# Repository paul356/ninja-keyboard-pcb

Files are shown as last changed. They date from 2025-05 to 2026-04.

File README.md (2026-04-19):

# How to use this project?

This pcb use some symbols and footprints that are not in the default KiCad library. I think the fp cache feature should cache these symbols and footprints. But in case you need them.
1. Keyswitch Kicad Library
2. Additional symbols and footprints are in the folder "user_added".

## 3D Case Design

A FreeCAD 3D model of the keyboard case is included in this project: `keyboard-case.FCStd`. You can open it with [FreeCAD](https://www.freecad.org/) to view, modify, or export the case design for 3D printing or CNC machining.

## License

This project is licensed under the [GNU General Public License v3.0](LICENSE).

You are free to use, study, modify, and distribute this project, provided that any derivative works are also distributed under the same GPL-3.0 license.

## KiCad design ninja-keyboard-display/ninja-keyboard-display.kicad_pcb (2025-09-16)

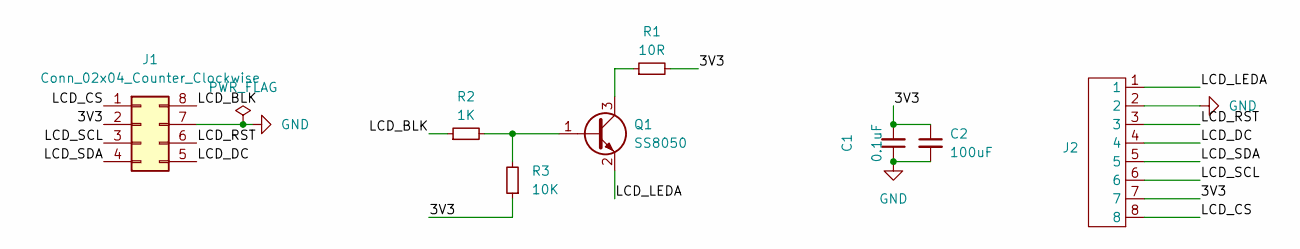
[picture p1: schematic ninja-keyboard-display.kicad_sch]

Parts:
C1: 0.1uF; C_0603_1608Metric; LCSC Part # C14663
C2: 100uF; CP_Elec_6.3x7.7
J1: Conn_02x04_Counter_Clockwise; PinHeader_2x04_P2.54mm_Vertical
J2: HanElectricity 1x8 P0.5mm drawer up-side; LCSC Part # C5362163
Q1: SS8050; SOT-23; LCSC Part # C2150
R1: 10R; R_0603_1608Metric; LCSC Part # C22859
R2: 1K; R_0603_1608Metric; LCSC Part # C21190
R3: 10K; R_0603_1608Metric; LCSC Part # C25804

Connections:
/3V3: C1.2, C2.1, J1.2, J2.7, R1.2, R3.1
/LCD_BLK: J1.8, R2.1
/LCD_CS: J1.1, J2.8
/LCD_DC: J1.5, J2.4
/LCD_LEDA: J2.1, Q1.2 (E)
/LCD_RST: J1.6, J2.3
/LCD_SCL: J1.3, J2.6
/LCD_SDA: J1.4, J2.5
GND: C1.1, C2.2, J1.7, J2.2
unnamed: Q1.1 (B), R2.2, R3.2
unnamed: Q1.3 (C), R1.1

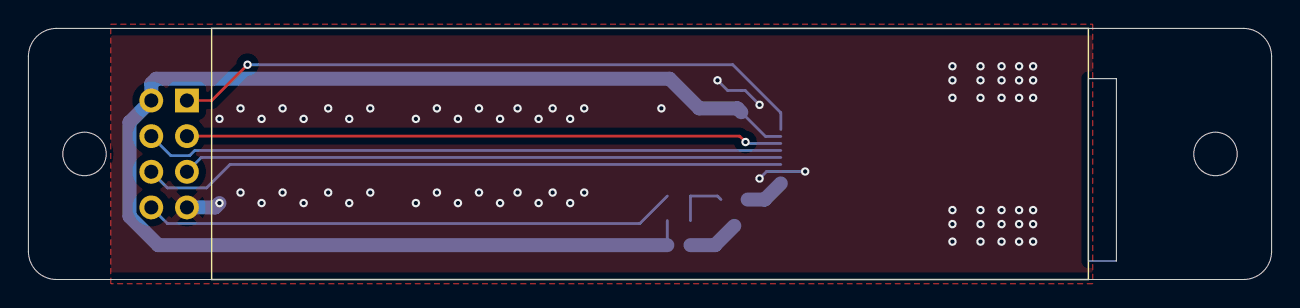
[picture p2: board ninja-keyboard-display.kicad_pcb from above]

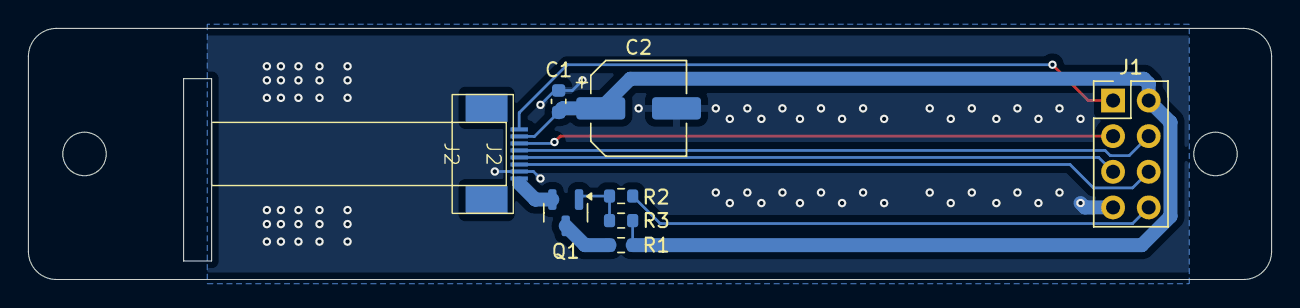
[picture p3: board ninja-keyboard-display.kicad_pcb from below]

Board: 2 copper layers, 88.6 x 17.9 mm, 8 parts (8 on the bottom side), 11 nets.

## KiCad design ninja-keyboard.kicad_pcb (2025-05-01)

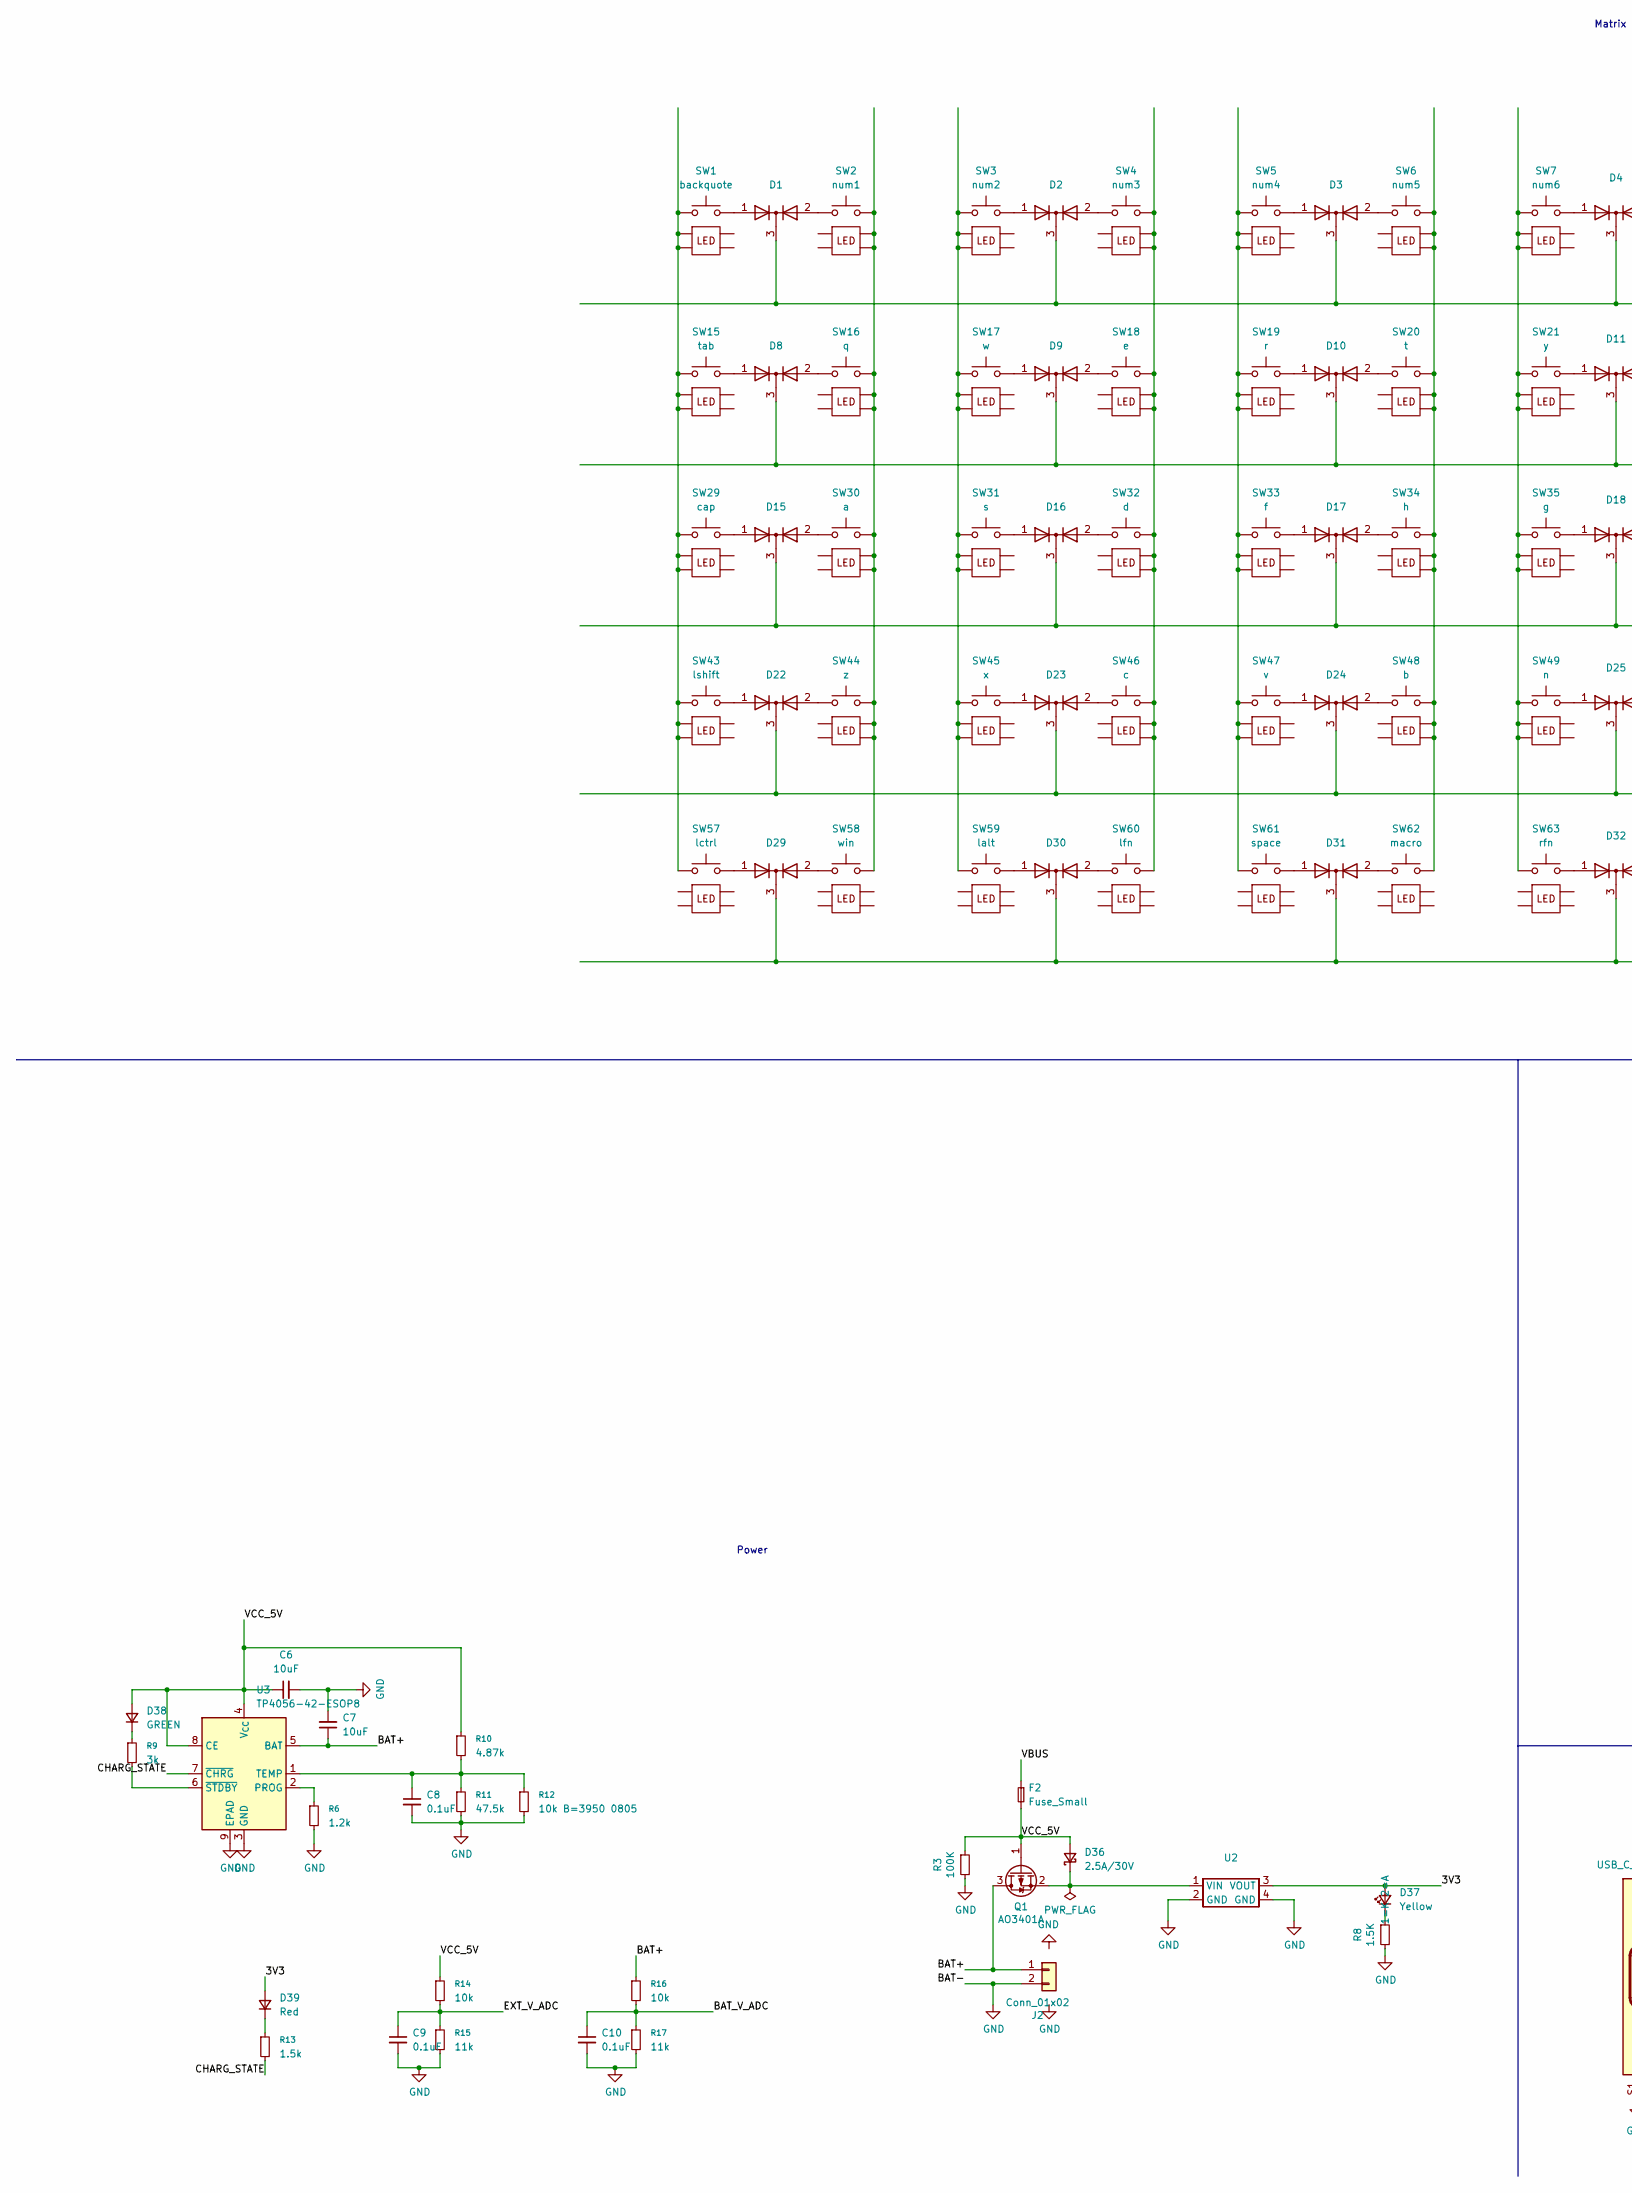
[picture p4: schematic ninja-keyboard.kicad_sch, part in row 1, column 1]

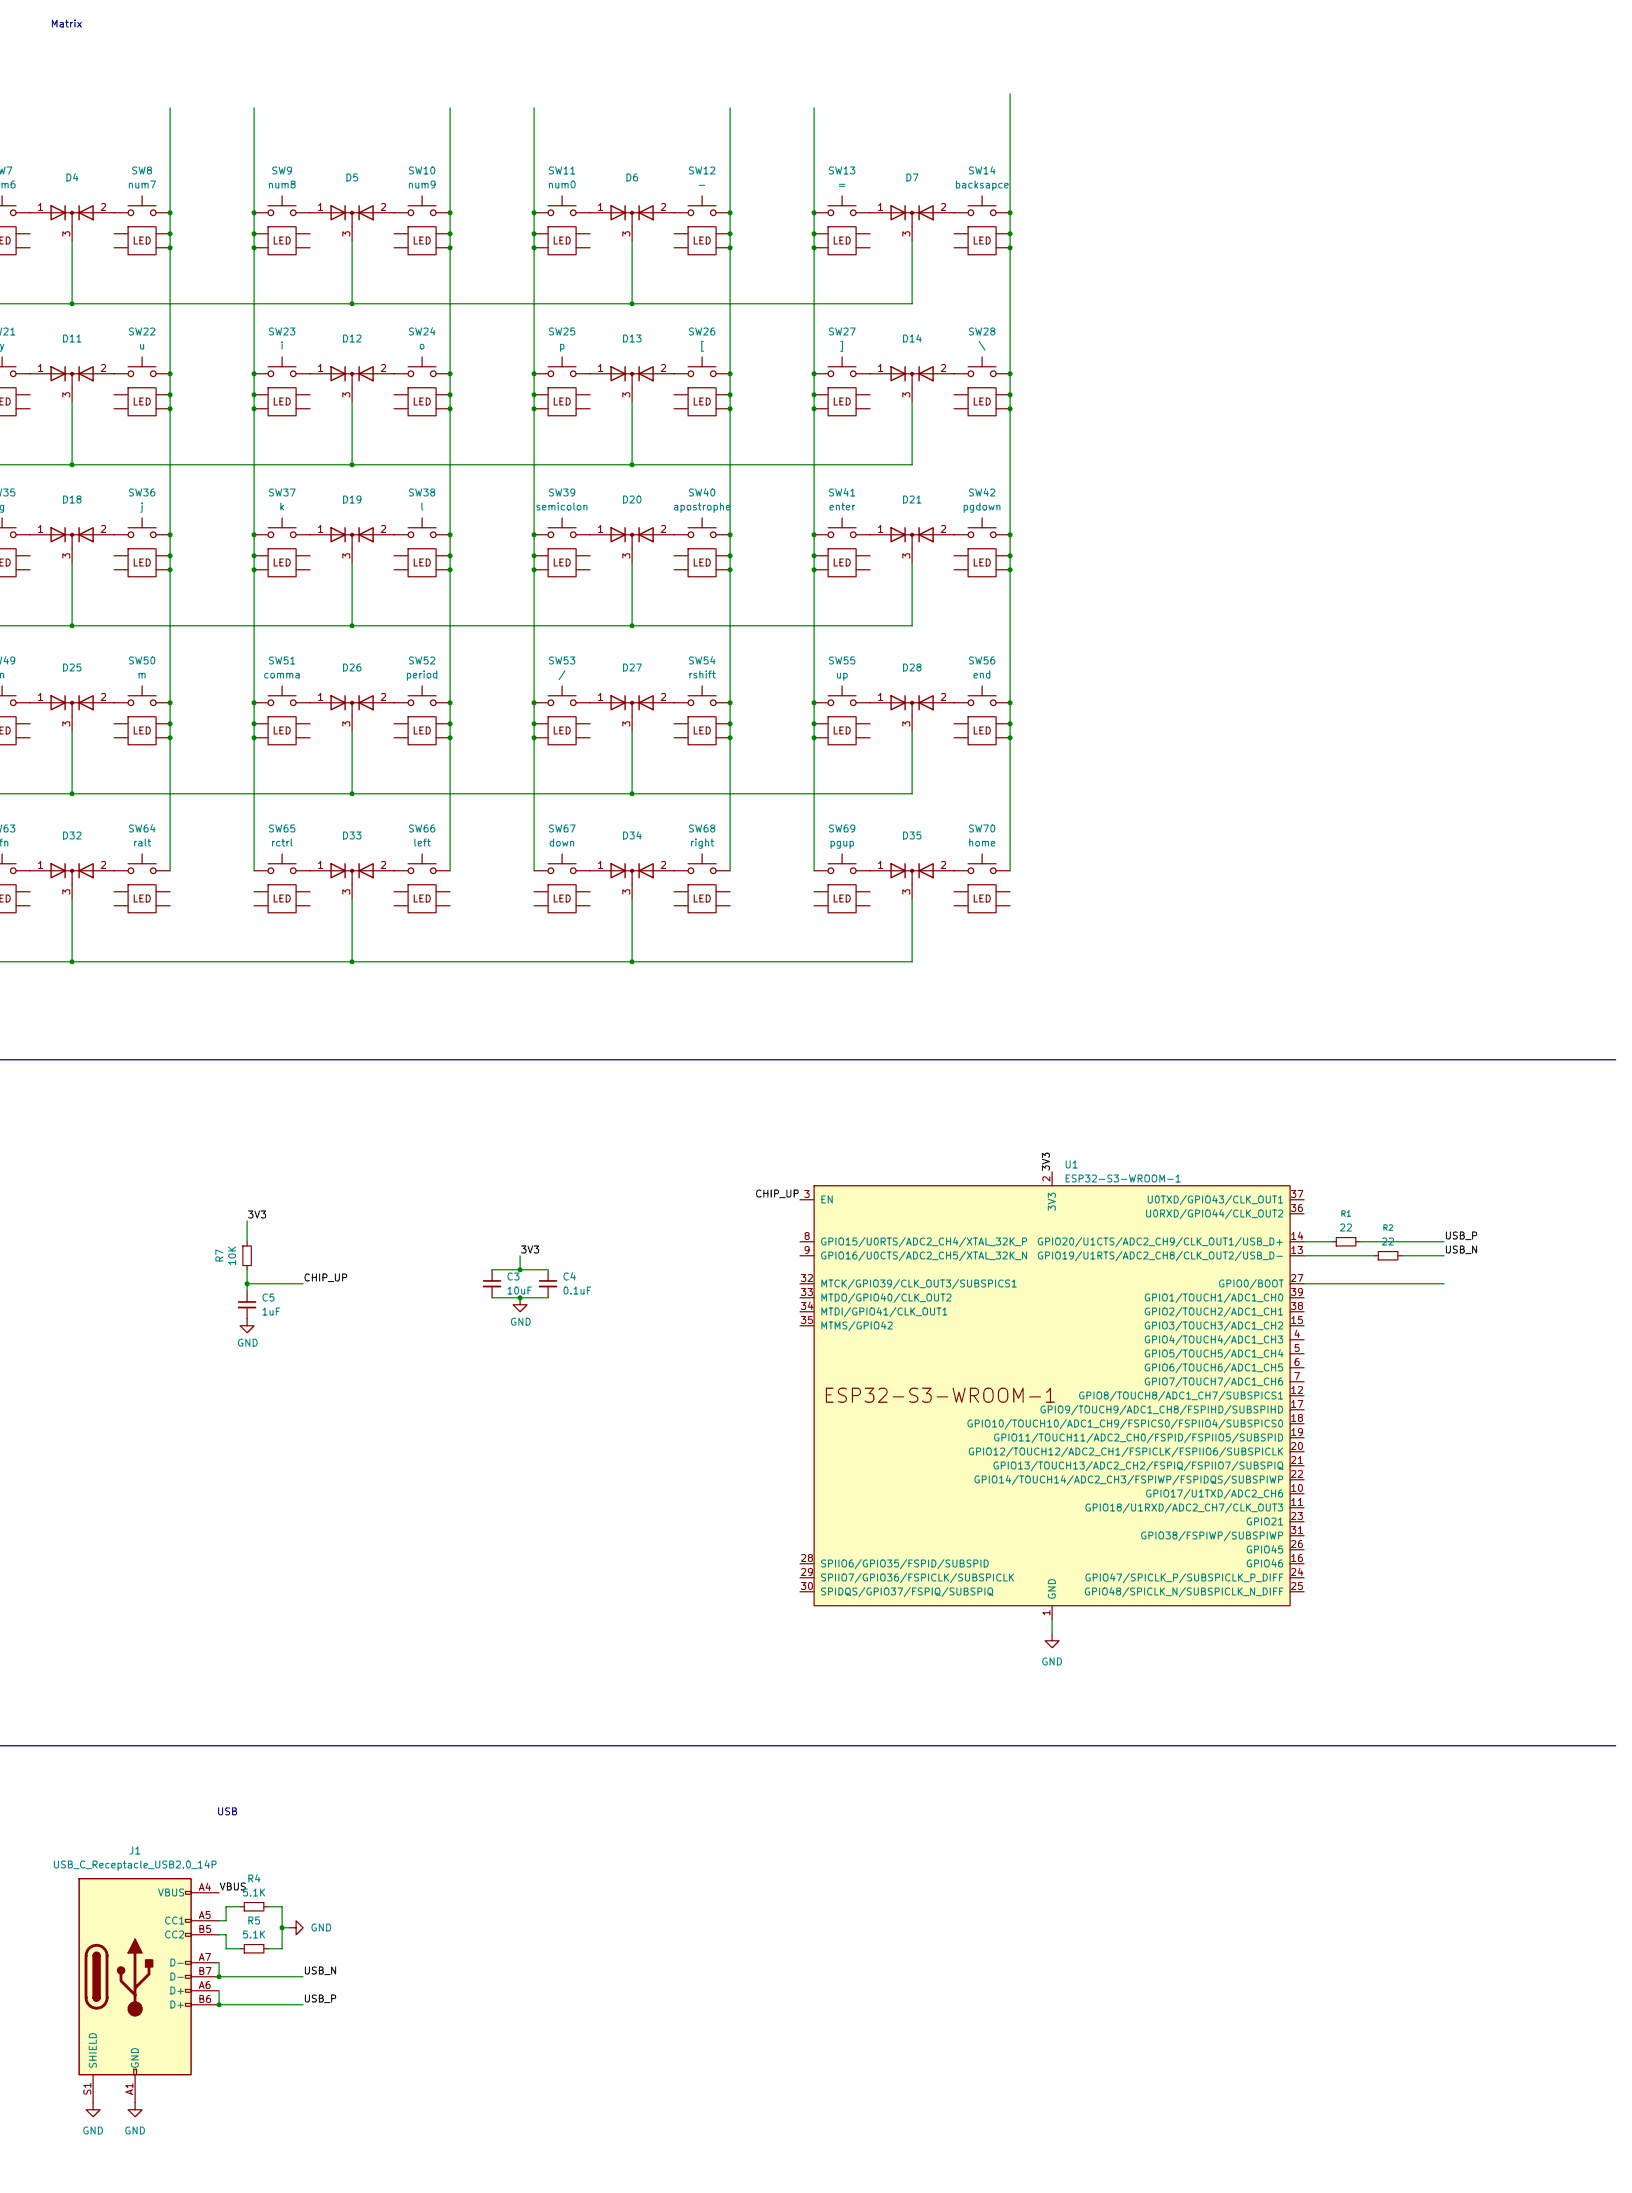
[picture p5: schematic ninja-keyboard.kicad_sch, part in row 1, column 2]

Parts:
C3: 10uF; C_0603_1608Metric; LCSC Part # C19702
C4: 0.1uF; C_0603_1608Metric; LCSC Part # C14663
C5: 1uF; C_0603_1608Metric; LCSC Part # C15849
C6, C7: 10uF; C_0603_1608Metric
C8, C9, C10: 0.1uF; C_0603_1608Metric
D1, D2, D3, D4, D5, D6, D7, D8, D9, D10, D11, D12, D13, D14, D15, D16, D17, D18, D19, D20, D21, D22, D23, D24, D25, D26, D27, D28, D29, D30, D31, D32, D33, D34, D35: SOT-23
D36: 2.5A/30V; D_SOD-123; LCSC Part # C8598
D37: Yellow; LED_0603_1608Metric; LCSC Part # C2286
D38: GREEN; LED_0603_1608Metric
D39: Red; LED_0603_1608Metric
F2: Fuse_Small; Fuse_0805_2012Metric; LCSC Part # C7472578
J1: USB_C_Receptacle_USB2.0_14P; USB_C_Receptacle_HRO_TYPE-C-31-M-12; LCSC Part # C165948
J2: Conn_01x02; PH 1x2 pin gap 2.0mm SMD socket; LCSC Part # C2845379
Q1: AO3401A; SOT-23; LCSC Part # C15127
R1, R2: 22; R_0603_1608Metric
R3: 100K; R_0603_1608Metric; LCSC Part # C25804
R4, R5: 5.1K; R_0603_1608Metric; LCSC Part # C23186
R6: 1.2k; R_0603_1608Metric
R7: 10K; R_0603_1608Metric; LCSC Part # C25804
R8: 1.5K; R_0603_1608Metric; LCSC Part # C25804
R9: 3k; R_0603_1608Metric
R10: 4.87k; R_0603_1608Metric
R11: 47.5k; R_0603_1608Metric
R12: 10k B=3950 0805; R_0805_2012Metric
R13: 1.5k; R_0603_1608Metric
R14, R16: 10k; R_0603_1608Metric
R15, R17: 11k; R_0603_1608Metric
SW1: backquote; SW_Hotswap_Kailh_MX_1.00u with led
SW2: num1; SW_Hotswap_Kailh_MX_1.00u with led
SW3: num2; SW_Hotswap_Kailh_MX_1.00u with led
SW4: num3; SW_Hotswap_Kailh_MX_1.00u with led
SW5: num4; SW_Hotswap_Kailh_MX_1.00u with led
SW6: num5; SW_Hotswap_Kailh_MX_1.00u with led
SW7: num6; SW_Hotswap_Kailh_MX_1.00u with led
SW8: num7; SW_Hotswap_Kailh_MX_1.00u with led
SW9: num8; SW_Hotswap_Kailh_MX_1.00u with led
SW10: num9; SW_Hotswap_Kailh_MX_1.00u with led
SW11: num0; SW_Hotswap_Kailh_MX_1.00u with led
SW12: -; SW_Hotswap_Kailh_MX_1.00u with led
SW13: =; SW_Hotswap_Kailh_MX_1.00u with led
SW14: backsapce; SW_Hotswap_Kailh_MX_1.75u with led
SW15: tab; SW_Hotswap_Kailh_MX_1.50u with led
SW16: q; SW_Hotswap_Kailh_MX_1.00u with led
SW17: w; SW_Hotswap_Kailh_MX_1.00u with led
SW18: e; SW_Hotswap_Kailh_MX_1.00u with led
SW19: r; SW_Hotswap_Kailh_MX_1.00u with led
SW20: t; SW_Hotswap_Kailh_MX_1.00u with led
SW21: y; SW_Hotswap_Kailh_MX_1.00u with led
SW22: u; SW_Hotswap_Kailh_MX_1.00u with led
SW23: i; SW_Hotswap_Kailh_MX_1.00u with led
SW24: o; SW_Hotswap_Kailh_MX_1.00u with led
SW25: p; SW_Hotswap_Kailh_MX_1.00u with led
SW26: [; SW_Hotswap_Kailh_MX_1.00u with led
SW27: ]; SW_Hotswap_Kailh_MX_1.00u with led
SW28: \; SW_Hotswap_Kailh_MX_1.25u with led
SW29: cap; SW_Hotswap_Kailh_MX_1.75u with led
SW30: a; SW_Hotswap_Kailh_MX_1.00u with led
SW31: s; SW_Hotswap_Kailh_MX_1.00u with led
SW32: d; SW_Hotswap_Kailh_MX_1.00u with led
SW33: f; SW_Hotswap_Kailh_MX_1.00u with led
SW34: h; SW_Hotswap_Kailh_MX_1.00u with led
SW35: g; SW_Hotswap_Kailh_MX_1.00u with led
SW36: j; SW_Hotswap_Kailh_MX_1.00u with led
SW37: k; SW_Hotswap_Kailh_MX_1.00u with led
SW38: l; SW_Hotswap_Kailh_MX_1.00u with led
SW39: semicolon; SW_Hotswap_Kailh_MX_1.00u with led
SW40: apostrophe; SW_Hotswap_Kailh_MX_1.00u with led
SW41: enter; SW_Hotswap_Kailh_MX_2.00u with led
SW42: pgdown; SW_Hotswap_Kailh_MX_1.00u with led
SW43: lshift; SW_Hotswap_Kailh_MX_2.25u with led
SW44: z; SW_Hotswap_Kailh_MX_1.00u with led
SW45: x; SW_Hotswap_Kailh_MX_1.00u with led
SW46: c; SW_Hotswap_Kailh_MX_1.00u with led
SW47: v; SW_Hotswap_Kailh_MX_1.00u with led
SW48: b; SW_Hotswap_Kailh_MX_1.00u with led
SW49: n; SW_Hotswap_Kailh_MX_1.00u with led
SW50: m; SW_Hotswap_Kailh_MX_1.00u with led
SW51: comma; SW_Hotswap_Kailh_MX_1.00u with led
SW52: period; SW_Hotswap_Kailh_MX_1.00u with led
SW53: /; SW_Hotswap_Kailh_MX_1.00u with led
SW54: rshift; SW_Hotswap_Kailh_MX_1.50u with led
SW55: up; SW_Hotswap_Kailh_MX_1.00u with led
SW56: end; SW_Hotswap_Kailh_MX_1.00u with led
SW57: lctrl; SW_Hotswap_Kailh_MX_1.25u with led
SW58: win; SW_Hotswap_Kailh_MX_1.25u with led
SW59: lalt; SW_Hotswap_Kailh_MX_1.25u with led
SW60: lfn; SW_Hotswap_Kailh_MX_1.00u with led
SW61: space; SW_Hotswap_Kailh_MX_2.25u with led
SW62: macro; SW_Hotswap_Kailh_MX_2.25u with led
SW63: rfn; SW_Hotswap_Kailh_MX_1.00u with led
SW64: ralt; SW_Hotswap_Kailh_MX_1.25u with led
SW65: rctrl; SW_Hotswap_Kailh_MX_1.25u with led
SW66: left; SW_Hotswap_Kailh_MX_1.00u with led
SW67: down; SW_Hotswap_Kailh_MX_1.00u with led
SW68: right; SW_Hotswap_Kailh_MX_1.00u with led
SW69: pgup; SW_Hotswap_Kailh_MX_1.00u with led
SW70: home; SW_Hotswap_Kailh_MX_1.00u with led
U1: ESP32-S3-WROOM-1
U2: XL63020-3.3
U3: TP4056-42-ESOP8; SOIC-8-1EP_3.9x4.9mm_P1.27mm_EP2.41x3.3mm_ThermalVias

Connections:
/3V3: C3.1, C4.1, D37.2 (A), D39.2 (A), R7.1, U1.2 (3V3), U2.3 (VOUT)
/BAT+: C7.1, J2.1, Q1.3 (D), R16.1, U3.5 (BAT)
/BAT_V_ADC: C10.1, R16.2, R17.1
/CHARG_STATE: R13.2, U3.7 (~CHRG)
/CHIP_UP: C5.1, R7.2, U1.3 (EN)
/EXT_V_ADC: C9.1, R14.2, R15.1
/USB_N: J1.A7 (D-), J1.B7 (D-), R2.2
/USB_P: J1.A6 (D+), J1.B6 (D+), R1.2
/VBUS: F2.1, J1.A4 (VBUS), J1.A9 (VBUS), J1.B4 (VBUS), J1.B9 (VBUS)
/VCC_5V: C6.1, D36.2 (A), D38.2 (A), F2.2, Q1.1 (G), R3.1, R10.1, R14.1, U3.4 (V_{CC}), U3.8 (CE)
GND: C3.2, C4.2, C5.2, C6.2, C7.2, C8.2, C9.2, C10.2, J1.A1 (GND), J1.A12 (GND), J1.B1 (GND), J1.B12 (GND), J1.S1 (SHIELD), J2.2, R3.2, R4.2, R5.2, R6.2, R8.2, R11.2, R12.2, R15.2, R17.2, U1.1 (GND), U1.40 (GND), U1.41 (GND), U2.2 (GND), U2.4 (GND), U3.3 (GND), U3.9 (EPAD)
unnamed: D1.1 (A), SW1.2
unnamed: D1.2 (A), SW2.1
unnamed: D1.3 (K), D2.3 (K), D3.3 (K), D4.3 (K), D5.3 (K), D6.3 (K), D7.3 (K)
unnamed: D2.1 (A), SW3.2
unnamed: D2.2 (A), SW4.1
unnamed: D3.1 (A), SW5.2
unnamed: D3.2 (A), SW6.1
unnamed: D4.1 (A), SW7.2
unnamed: D4.2 (A), SW8.1
unnamed: D5.1 (A), SW9.2
unnamed: D5.2 (A), SW10.1
unnamed: D6.1 (A), SW11.2
unnamed: D6.2 (A), SW12.1
unnamed: D7.1 (A), SW13.2
unnamed: D7.2 (A), SW14.1
unnamed: D8.1 (A), SW15.2
unnamed: D8.2 (A), SW16.1
unnamed: D9.1 (A), SW17.2
unnamed: D9.2 (A), SW18.1
unnamed: D10.1 (A), SW19.2
unnamed: D10.2 (A), SW20.1
unnamed: D8.3 (K), D9.3 (K), D10.3 (K), D11.3 (K), D12.3 (K), D13.3 (K), D14.3 (K)
unnamed: D11.1 (A), SW21.2
unnamed: D11.2 (A), SW22.1
unnamed: D12.1 (A), SW23.2
unnamed: D12.2 (A), SW24.1
unnamed: D13.1 (A), SW25.2
unnamed: D13.2 (A), SW26.1
unnamed: D14.1 (A), SW27.2
unnamed: D14.2 (A), SW28.1
unnamed: D15.1 (A), SW29.2
unnamed: D15.2 (A), SW30.1
unnamed: D15.3 (K), D16.3 (K), D17.3 (K), D18.3 (K), D19.3 (K), D20.3 (K), D21.3 (K)
unnamed: D16.1 (A), SW31.2
unnamed: D16.2 (A), SW32.1
unnamed: D17.1 (A), SW33.2
unnamed: D17.2 (A), SW34.1
unnamed: D18.1 (A), SW35.2
unnamed: D18.2 (A), SW36.1
unnamed: D19.1 (A), SW37.2
unnamed: D19.2 (A), SW38.1
unnamed: D20.1 (A), SW39.2
unnamed: D20.2 (A), SW40.1
unnamed: D21.1 (A), SW41.2
unnamed: D21.2 (A), SW42.1
unnamed: D22.1 (A), SW43.2
unnamed: D22.2 (A), SW44.1
unnamed: D22.3 (K), D23.3 (K), D24.3 (K), D25.3 (K), D26.3 (K), D27.3 (K), D28.3 (K)
unnamed: D23.1 (A), SW45.2
unnamed: D23.2 (A), SW46.1
unnamed: D24.1 (A), SW47.2
unnamed: D24.2 (A), SW48.1
unnamed: D25.1 (A), SW49.2
unnamed: D25.2 (A), SW50.1
unnamed: D26.1 (A), SW51.2
unnamed: D26.2 (A), SW52.1
unnamed: D27.1 (A), SW53.2
unnamed: D27.2 (A), SW54.1
unnamed: D28.1 (A), SW55.2
unnamed: D28.2 (A), SW56.1
unnamed: D29.1 (A), SW57.2
unnamed: D29.2 (A), SW58.1
unnamed: D29.3 (K), D30.3 (K), D31.3 (K), D32.3 (K), D33.3 (K), D34.3 (K), D35.3 (K)
unnamed: D30.1 (A), SW59.2
unnamed: D30.2 (A), SW60.1
unnamed: D31.1 (A), SW61.2
unnamed: D31.2 (A), SW62.1
unnamed: D32.1 (A), SW63.2
unnamed: D32.2 (A), SW64.1
unnamed: D33.1 (A), SW65.2
unnamed: D33.2 (A), SW66.1
unnamed: D34.1 (A), SW67.2
unnamed: D34.2 (A), SW68.1
unnamed: D35.1 (A), SW69.2
unnamed: D35.2 (A), SW70.1
unnamed: D36.1 (K), Q1.2 (S), U2.1 (VIN)
unnamed: D37.1 (K), R8.1
unnamed: D38.1 (K), R9.1
unnamed: D39.1 (K), R13.1
unnamed: J1.A5 (CC1), R4.1
unnamed: J1.B5 (CC2), R5.1
unnamed: SW1.1, SW1.3 (VDD), SW1.4 (DOUT), SW15.1, SW15.3 (VDD), SW15.4 (DOUT), SW29.1, SW29.3 (VDD), SW29.4 (DOUT), SW43.1, SW43.3 (VDD), SW43.4 (DOUT), SW57.1
unnamed: SW10.2, SW10.5 (DIN), SW10.6 (GND), SW24.2, SW24.5 (DIN), SW24.6 (GND), SW38.2, SW38.5 (DIN), SW38.6 (GND), SW52.2, SW52.5 (DIN), SW52.6 (GND), SW66.2
unnamed: SW11.1, SW11.3 (VDD), SW11.4 (DOUT), SW25.1, SW25.3 (VDD), SW25.4 (DOUT), SW39.1, SW39.3 (VDD), SW39.4 (DOUT), SW53.1, SW53.3 (VDD), SW53.4 (DOUT), SW67.1
unnamed: SW12.2, SW12.5 (DIN), SW12.6 (GND), SW26.2, SW26.5 (DIN), SW26.6 (GND), SW40.2, SW40.5 (DIN), SW40.6 (GND), SW54.2, SW54.5 (DIN), SW54.6 (GND), SW68.2
unnamed: SW13.1, SW13.3 (VDD), SW13.4 (DOUT), SW27.1, SW27.3 (VDD), SW27.4 (DOUT), SW41.1, SW41.3 (VDD), SW41.4 (DOUT), SW55.1, SW55.3 (VDD), SW55.4 (DOUT), SW69.1
unnamed: SW14.2, SW14.5 (DIN), SW14.6 (GND), SW28.2, SW28.5 (DIN), SW28.6 (GND), SW42.2, SW42.5 (DIN), SW42.6 (GND), SW56.2, SW56.5 (DIN), SW56.6 (GND), SW70.2
unnamed: SW2.2, SW2.5 (DIN), SW2.6 (GND), SW16.2, SW16.5 (DIN), SW16.6 (GND), SW30.2, SW30.5 (DIN), SW30.6 (GND), SW44.2, SW44.5 (DIN), SW44.6 (GND), SW58.2
unnamed: SW3.1, SW3.3 (VDD), SW3.4 (DOUT), SW17.1, SW17.3 (VDD), SW17.4 (DOUT), SW31.1, SW31.3 (VDD), SW31.4 (DOUT), SW45.1, SW45.3 (VDD), SW45.4 (DOUT), SW59.1
unnamed: SW4.2, SW4.5 (DIN), SW4.6 (GND), SW18.2, SW18.5 (DIN), SW18.6 (GND), SW32.2, SW32.5 (DIN), SW32.6 (GND), SW46.2, SW46.5 (DIN), SW46.6 (GND), SW60.2
unnamed: SW5.1, SW5.3 (VDD), SW5.4 (DOUT), SW19.1, SW19.3 (VDD), SW19.4 (DOUT), SW33.1, SW33.3 (VDD), SW33.4 (DOUT), SW47.1, SW47.3 (VDD), SW47.4 (DOUT), SW61.1
unnamed: SW6.2, SW6.5 (DIN), SW6.6 (GND), SW20.2, SW20.5 (DIN), SW20.6 (GND), SW34.2, SW34.5 (DIN), SW34.6 (GND), SW48.2, SW48.5 (DIN), SW48.6 (GND), SW62.2
unnamed: SW7.1, SW7.3 (VDD), SW7.4 (DOUT), SW21.1, SW21.3 (VDD), SW21.4 (DOUT), SW35.1, SW35.3 (VDD), SW35.4 (DOUT), SW49.1, SW49.3 (VDD), SW49.4 (DOUT), SW63.1
unnamed: SW8.2, SW8.5 (DIN), SW8.6 (GND), SW22.2, SW22.5 (DIN), SW22.6 (GND), SW36.2, SW36.5 (DIN), SW36.6 (GND), SW50.2, SW50.5 (DIN), SW50.6 (GND), SW64.2
unnamed: SW9.1, SW9.3 (VDD), SW9.4 (DOUT), SW23.1, SW23.3 (VDD), SW23.4 (DOUT), SW37.1, SW37.3 (VDD), SW37.4 (DOUT), SW51.1, SW51.3 (VDD), SW51.4 (DOUT), SW65.1
unnamed: R2.1, U1.13 (GPIO19/U1RTS/ADC2_CH8/CLK_OUT2/USB_D-)
unnamed: R1.1, U1.14 (GPIO20/U1CTS/ADC2_CH9/CLK_OUT1/USB_D+)
unnamed: R6.1, U3.2 (PROG)
unnamed: C8.1, R10.2, R11.1, R12.1, U3.1 (TEMP)
unnamed: R9.2, U3.6 (~STDBY)

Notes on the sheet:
Power
Matrix
USB

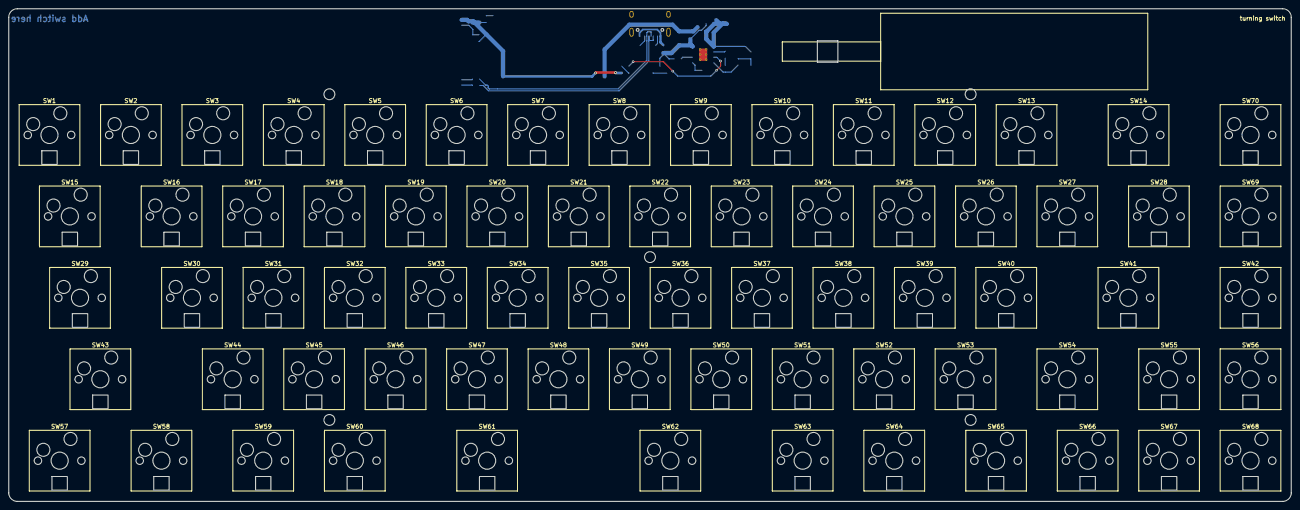
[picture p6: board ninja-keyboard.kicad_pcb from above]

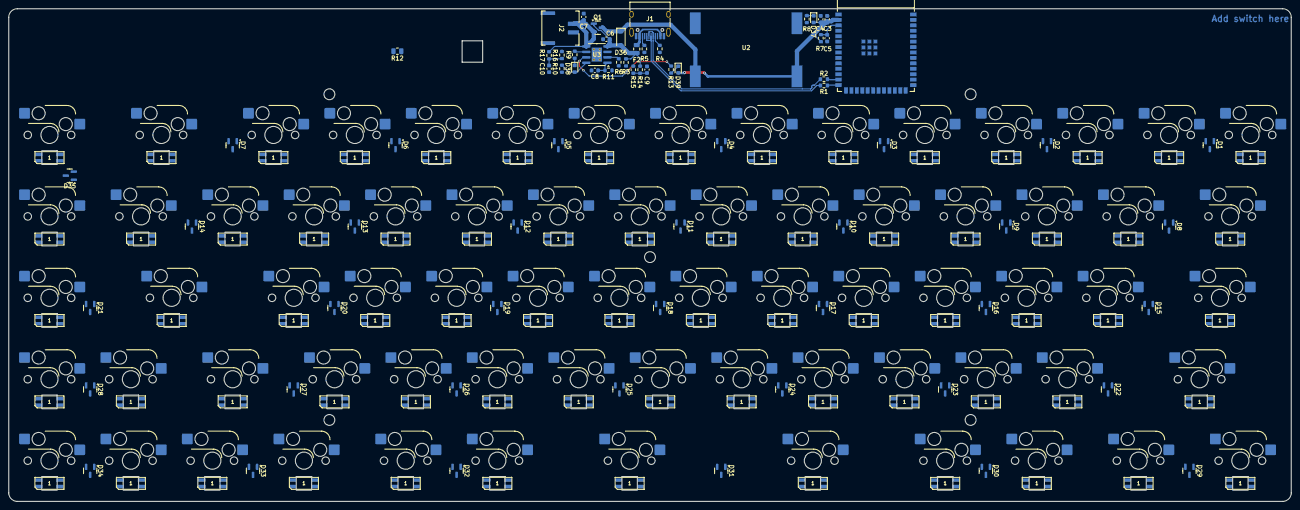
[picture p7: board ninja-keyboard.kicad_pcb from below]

Board: 2 copper layers, 300.0 x 115.3 mm, 141 parts (71 on the bottom side), 111 nets.

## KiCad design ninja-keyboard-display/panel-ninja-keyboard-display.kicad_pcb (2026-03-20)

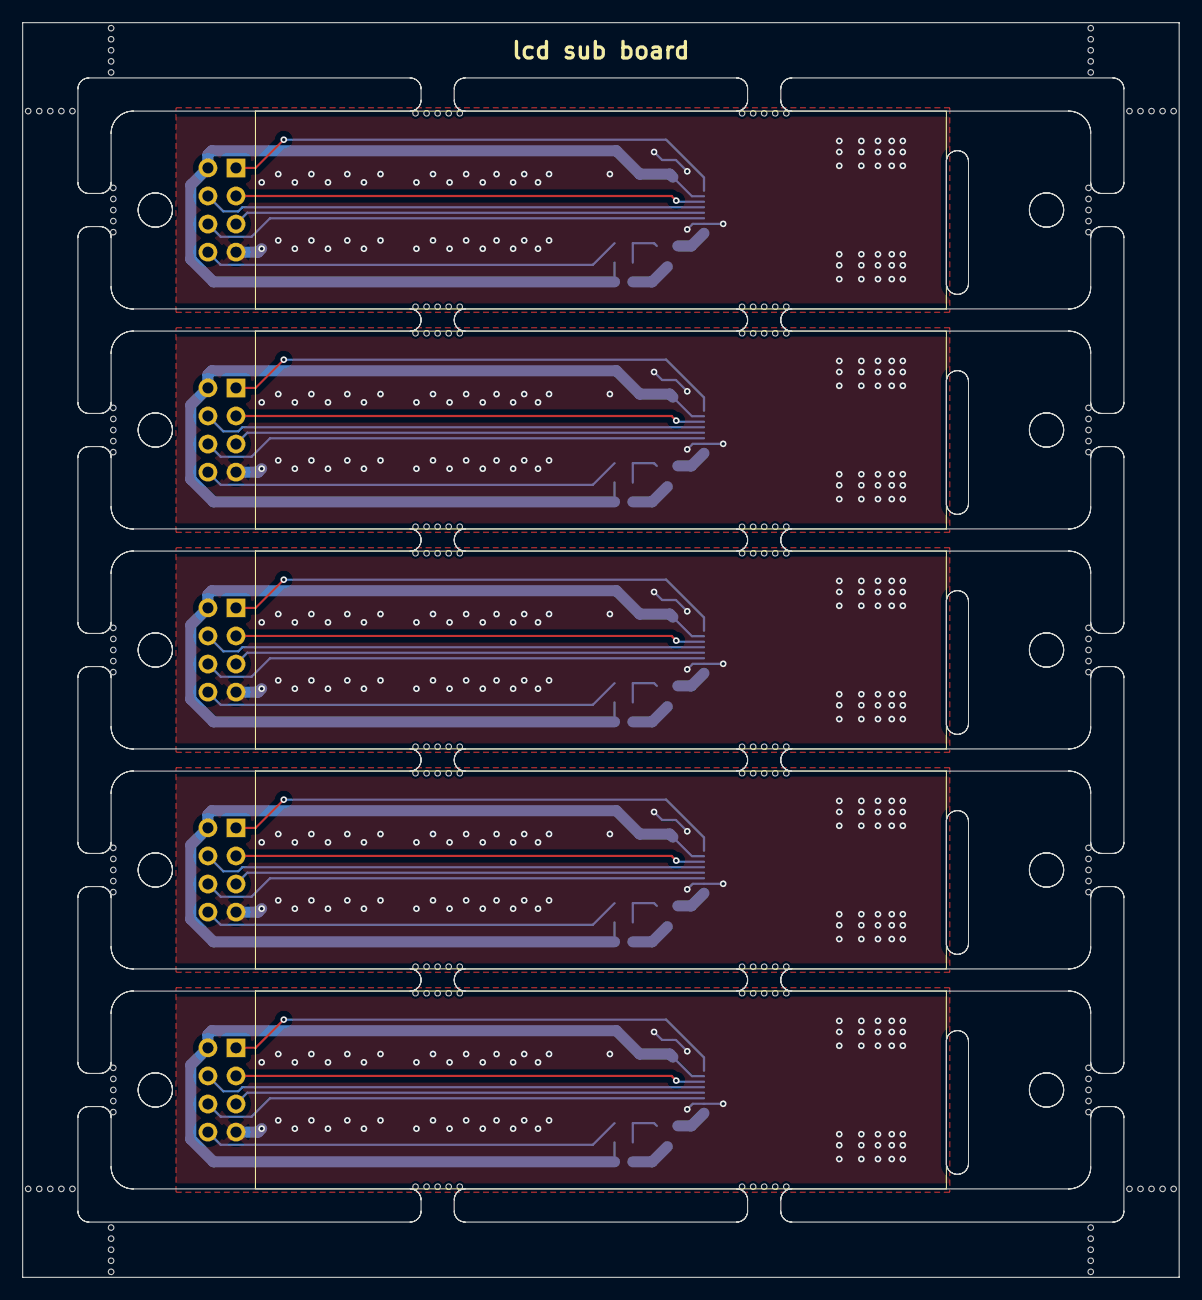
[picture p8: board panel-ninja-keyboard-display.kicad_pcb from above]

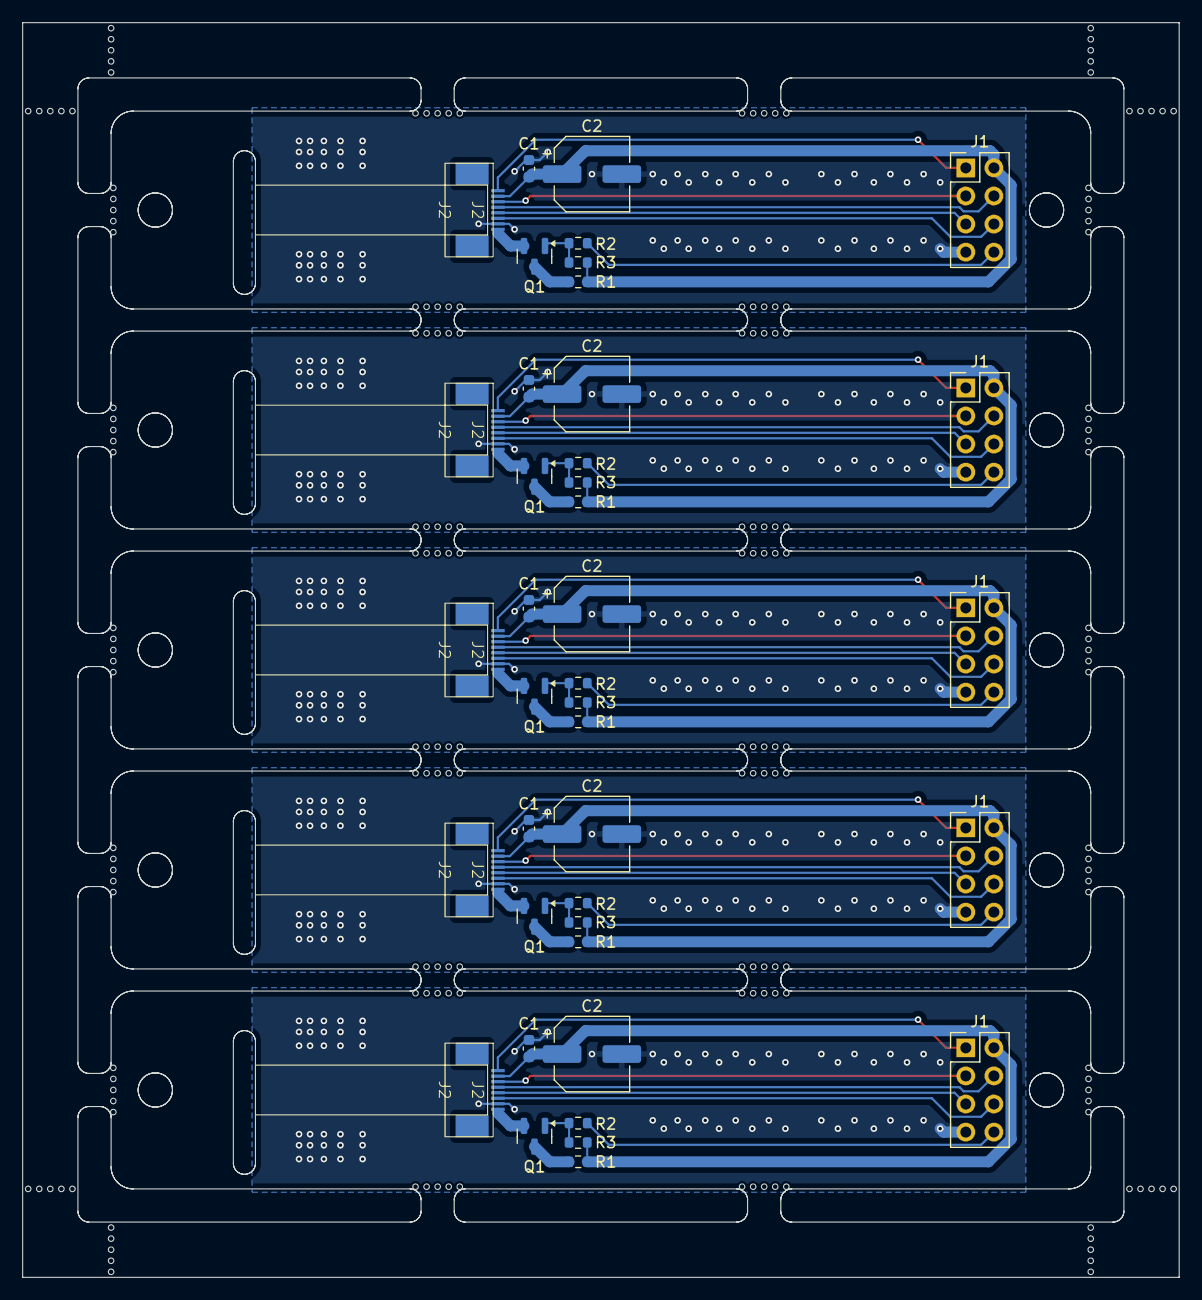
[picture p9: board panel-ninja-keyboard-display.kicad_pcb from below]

Board: 2 copper layers, 104.6 x 113.5 mm, 230 parts (40 on the bottom side), 55 nets.

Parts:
C1, C1#2, C1#3, C1#4, C1#5: 0.1uF; C_0603_1608Metric
C2, C2#2, C2#3, C2#4, C2#5: 100uF; CP_Elec_6.3x7.7
J1, J1#2, J1#3, J1#4, J1#5: Conn_02x04_Counter_Clockwise; PinHeader_2x04_P2.54mm_Vertical
J2, J2#2, J2#3, J2#4, J2#5: HanElectricity 1x8 P0.5mm drawer up-side
KiKit_MB_1_1, KiKit_MB_1_2, KiKit_MB_1_3, KiKit_MB_1_4, KiKit_MB_1_5, KiKit_MB_2_1, KiKit_MB_2_2, KiKit_MB_2_3, KiKit_MB_2_4, KiKit_MB_2_5, KiKit_MB_3_1, KiKit_MB_3_2, KiKit_MB_3_3, KiKit_MB_3_4, KiKit_MB_3_5, KiKit_MB_4_1, KiKit_MB_4_2, KiKit_MB_4_3, KiKit_MB_4_4, KiKit_MB_4_5, KiKit_MB_5_1, KiKit_MB_5_2, KiKit_MB_5_3, KiKit_MB_5_4, KiKit_MB_5_5, KiKit_MB_6_1, KiKit_MB_6_2, KiKit_MB_6_3, KiKit_MB_6_4, KiKit_MB_6_5, KiKit_MB_7_1, KiKit_MB_7_2, KiKit_MB_7_3, KiKit_MB_7_4, KiKit_MB_7_5, KiKit_MB_8_1, KiKit_MB_8_2, KiKit_MB_8_3, KiKit_MB_8_4, KiKit_MB_8_5, KiKit_MB_9_1, KiKit_MB_9_2, KiKit_MB_9_3, KiKit_MB_9_4, KiKit_MB_9_5, KiKit_MB_10_1, KiKit_MB_10_2, KiKit_MB_10_3, KiKit_MB_10_4, KiKit_MB_10_5, KiKit_MB_11_1, KiKit_MB_11_2, KiKit_MB_11_3, KiKit_MB_11_4, KiKit_MB_11_5, KiKit_MB_12_1, KiKit_MB_12_2, KiKit_MB_12_3, KiKit_MB_12_4, KiKit_MB_12_5, KiKit_MB_13_1, KiKit_MB_13_2, KiKit_MB_13_3, KiKit_MB_13_4, KiKit_MB_13_5, KiKit_MB_14_1, KiKit_MB_14_2, KiKit_MB_14_3, KiKit_MB_14_4, KiKit_MB_14_5, KiKit_MB_15_1, KiKit_MB_15_2, KiKit_MB_15_3, KiKit_MB_15_4, KiKit_MB_15_5, KiKit_MB_16_1, KiKit_MB_16_2, KiKit_MB_16_3, KiKit_MB_16_4, KiKit_MB_16_5, KiKit_MB_17_1, KiKit_MB_17_2, KiKit_MB_17_3, KiKit_MB_17_4, KiKit_MB_17_5, KiKit_MB_18_1, KiKit_MB_18_2, KiKit_MB_18_3, KiKit_MB_18_4, KiKit_MB_18_5, KiKit_MB_19_1, KiKit_MB_19_2, KiKit_MB_19_3, KiKit_MB_19_4, KiKit_MB_19_5, KiKit_MB_20_1, KiKit_MB_20_2, KiKit_MB_20_3, KiKit_MB_20_4, KiKit_MB_20_5, KiKit_MB_21_1, KiKit_MB_21_2, KiKit_MB_21_3, KiKit_MB_21_4, KiKit_MB_21_5, KiKit_MB_22_1, KiKit_MB_22_2, KiKit_MB_22_3, KiKit_MB_22_4, KiKit_MB_22_5, KiKit_MB_23_1, KiKit_MB_23_2, KiKit_MB_23_3, KiKit_MB_23_4, KiKit_MB_23_5, KiKit_MB_24_1, KiKit_MB_24_2, KiKit_MB_24_3, KiKit_MB_24_4, KiKit_MB_24_5, KiKit_MB_25_1, KiKit_MB_25_2, KiKit_MB_25_3, KiKit_MB_25_4, KiKit_MB_25_5, KiKit_MB_26_1, KiKit_MB_26_2, KiKit_MB_26_3, KiKit_MB_26_4, KiKit_MB_26_5, KiKit_MB_27_1, KiKit_MB_27_2, KiKit_MB_27_3, KiKit_MB_27_4, KiKit_MB_27_5, KiKit_MB_28_1, KiKit_MB_28_2, KiKit_MB_28_3, KiKit_MB_28_4, KiKit_MB_28_5, KiKit_MB_29_1, KiKit_MB_29_2, KiKit_MB_29_3, KiKit_MB_29_4, KiKit_MB_29_5, KiKit_MB_30_1, KiKit_MB_30_2, KiKit_MB_30_3, KiKit_MB_30_4, KiKit_MB_30_5, KiKit_MB_31_2, KiKit_MB_31_3, KiKit_MB_31_4, KiKit_MB_31_5, KiKit_MB_31_6, KiKit_MB_32_2, KiKit_MB_32_3, KiKit_MB_32_4, KiKit_MB_32_5, KiKit_MB_32_6, KiKit_MB_33_2, KiKit_MB_33_3, KiKit_MB_33_4, KiKit_MB_33_5, KiKit_MB_33_6, KiKit_MB_34_2, KiKit_MB_34_3, KiKit_MB_34_4, KiKit_MB_34_5, KiKit_MB_34_6, KiKit_MB_35_2, KiKit_MB_35_3, KiKit_MB_35_4, KiKit_MB_35_5, KiKit_MB_35_6, KiKit_MB_36_2, KiKit_MB_36_3, KiKit_MB_36_4, KiKit_MB_36_5, KiKit_MB_36_6, KiKit_MB_37_2, KiKit_MB_37_3, KiKit_MB_37_4, KiKit_MB_37_5, KiKit_MB_37_6, KiKit_MB_38_2, KiKit_MB_38_3, KiKit_MB_38_4, KiKit_MB_38_5, KiKit_MB_38_6: NPTH
Q1, Q1#2, Q1#3, Q1#4, Q1#5: SS8050; SOT-23
R1, R1#2, R1#3, R1#4, R1#5: 10R; R_0603_1608Metric
R2, R2#2, R2#3, R2#4, R2#5: 1K; R_0603_1608Metric
R3, R3#2, R3#3, R3#4, R3#5: 10K; R_0603_1608Metric

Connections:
Board_0-/3V3: C1#3.2, C2#3.1, J1#2.2, J2.7, R1#3.2, R3.1
Board_0-/LCD_BLK: J1#2.8, R2.1
Board_0-/LCD_CS: J1#2.1, J2.8
Board_0-/LCD_DC: J1#2.5, J2.4
Board_0-/LCD_LEDA: J2.1, Q1#4.2 (E)
Board_0-/LCD_RST: J1#2.6, J2.3
Board_0-/LCD_SCL: J1#2.3, J2.6
Board_0-/LCD_SDA: J1#2.4, J2.5
Board_0-GND: C1#3.1, C2#3.2, J1#2.7, J2.2
Board_0-Net-(Q1-B): Q1#4.1 (B), R2.2, R3.2
Board_0-Net-(Q1-C): Q1#4.3 (C), R1#3.1
Board_1-/3V3: C1#2.2, C2#5.1, J1#5.2, J2#2.7, R1#5.2, R3#3.1
Board_1-/LCD_BLK: J1#5.8, R2#5.1
Board_1-/LCD_CS: J1#5.1, J2#2.8
Board_1-/LCD_DC: J1#5.5, J2#2.4
Board_1-/LCD_LEDA: J2#2.1, Q1#5.2 (E)
Board_1-/LCD_RST: J1#5.6, J2#2.3
Board_1-/LCD_SCL: J1#5.3, J2#2.6
Board_1-/LCD_SDA: J1#5.4, J2#2.5
Board_1-GND: C1#2.1, C2#5.2, J1#5.7, J2#2.2
Board_1-Net-(Q1-B): Q1#5.1 (B), R2#5.2, R3#3.2
Board_1-Net-(Q1-C): Q1#5.3 (C), R1#5.1
Board_2-/3V3: C1#5.2, C2.1, J1#3.2, J2#3.7, R1#4.2, R3#4.1
Board_2-/LCD_BLK: J1#3.8, R2#2.1
Board_2-/LCD_CS: J1#3.1, J2#3.8
Board_2-/LCD_DC: J1#3.5, J2#3.4
Board_2-/LCD_LEDA: J2#3.1, Q1#2.2 (E)
Board_2-/LCD_RST: J1#3.6, J2#3.3
Board_2-/LCD_SCL: J1#3.3, J2#3.6
Board_2-/LCD_SDA: J1#3.4, J2#3.5
Board_2-GND: C1#5.1, C2.2, J1#3.7, J2#3.2
Board_2-Net-(Q1-B): Q1#2.1 (B), R2#2.2, R3#4.2
Board_2-Net-(Q1-C): Q1#2.3 (C), R1#4.1
Board_3-/3V3: C1#4.2, C2#4.1, J1#4.2, J2#4.7, R1.2, R3#5.1
Board_3-/LCD_BLK: J1#4.8, R2#4.1
Board_3-/LCD_CS: J1#4.1, J2#4.8
Board_3-/LCD_DC: J1#4.5, J2#4.4
Board_3-/LCD_LEDA: J2#4.1, Q1#3.2 (E)
Board_3-/LCD_RST: J1#4.6, J2#4.3
Board_3-/LCD_SCL: J1#4.3, J2#4.6
Board_3-/LCD_SDA: J1#4.4, J2#4.5
Board_3-GND: C1#4.1, C2#4.2, J1#4.7, J2#4.2
Board_3-Net-(Q1-B): Q1#3.1 (B), R2#4.2, R3#5.2
Board_3-Net-(Q1-C): Q1#3.3 (C), R1.1
Board_4-/3V3: C1.2, C2#2.1, J1.2, J2#5.7, R1#2.2, R3#2.1
Board_4-/LCD_BLK: J1.8, R2#3.1
Board_4-/LCD_CS: J1.1, J2#5.8
Board_4-/LCD_DC: J1.5, J2#5.4
Board_4-/LCD_LEDA: J2#5.1, Q1.2 (E)
Board_4-/LCD_RST: J1.6, J2#5.3
Board_4-/LCD_SCL: J1.3, J2#5.6
Board_4-/LCD_SDA: J1.4, J2#5.5
Board_4-GND: C1.1, C2#2.2, J1.7, J2#5.2
Board_4-Net-(Q1-B): Q1.1 (B), R2#3.2, R3#2.2
Board_4-Net-(Q1-C): Q1.3 (C), R1#2.1

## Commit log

2025-04-30 Before removing the tp4056-42 because I can't use AMS1117 with a 3.7v battery
    [ninja-keyboard.kicad_pcb, ninja-keyboard.kicad_sch]
2025-04-30 Lay the components on the board, but haven't connect them with traces
    [ninja-keyboard.kicad_pcb, ninja-keyboard.kicad_sch]
2025-05-01 commit before trying to fix stuck kicad
    [ninja-keyboard.kicad_pcb, ninja-keyboard.kicad_sch]
2025-05-01 use export netlist feature for now
    [ninja-keyboard.kicad_pcb, ninja-keyboard.kicad_sch]
2025-05-05 Before add two inner layers and route with freeroute
    [ninja-keyboard.kicad_sch]
2025-05-06 Add a rotatory encoder and a switch for battery
    [ninja-keyboard.kicad_sch]
2025-05-06 Relocate the battery switch
2025-05-14 Remove fuse
    [ninja-keyboard.kicad_sch]
2025-06-06 Remove key stablizer holes
    [ninja-keyboard.kicad_sch]
2025-06-06 Seperate capacitors and LEDs from the mechanical keys
    [ninja-keyboard.kicad_sch]
2025-06-06 position LEDs and capacitors on PCB
2025-06-07 Modify LCD socket pin definition
    [ninja-keyboard.kicad_sch]
2025-06-24 Add JLC component serial numbers
    [ninja-keyboard.kicad_sch]
2025-06-27 Change board dimension to default 60% layout
    [ninja-keyboard.kicad_sch]
2025-07-31 1. Widen tracks for smart leds. 2. Increase output pins for smart leds. 3. Use EC11 for knob switch
    [ninja-keyboard.kicad_sch]
2025-07-31 Fix position output of switches and smart leds to correct side
    [ninja-keyboard.kicad_sch]
2025-08-23 Fix some LSCS# Numbers
    [ninja-keyboard.kicad_sch]
2025-09-13 remove parts belong to the lcd sub board
    [ninja-keyboard.kicad_sch]
2025-09-15 Add space and screw holes for LCD sub board
2025-09-15 Add a LCD sub board
    [ninja-keyboard-display.kicad_pcb, ninja-keyboard-display.kicad_sch, ninja-keyboard.kicad_sch]
2025-09-16 Fix DRC errors: connect zone fields
    [ninja-keyboard-display.kicad_pcb]
2025-09-27 Add a 2 millimeter gap between keys and lcd
2025-11-09 1. Use built in NTC resistors. 2. Correct the position of SL28.
    [ninja-keyboard.kicad_sch]
2025-11-10 Add JLC sn to 1x3P 2mm connector
    [ninja-keyboard.kicad_sch]
2026-03-20 Save changes for the dev board.
    [panel-ninja-keyboard-display.kicad_pcb]
2026-04-17 Add LICENSE, README, README_CN, and user-added footprints/symbols
2026-04-19 docs: add FreeCAD 3D case design section to README files
